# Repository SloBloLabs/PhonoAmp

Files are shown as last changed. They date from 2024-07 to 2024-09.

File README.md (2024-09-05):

# Phono Amp

Phono Amp is a RIAA compliant pre-amplifier circuit that I built into my good old Dual 626, because my living room receiver does not provide phono level inputs.

It is a very simple and straighforward design. Using KiCad simulator, component values were optimized to preserve both a nice bottom end and brilliant treble on the output.

All simulation files are contained and available in this repository.

## Small Signal Analysis from KiCad simulation
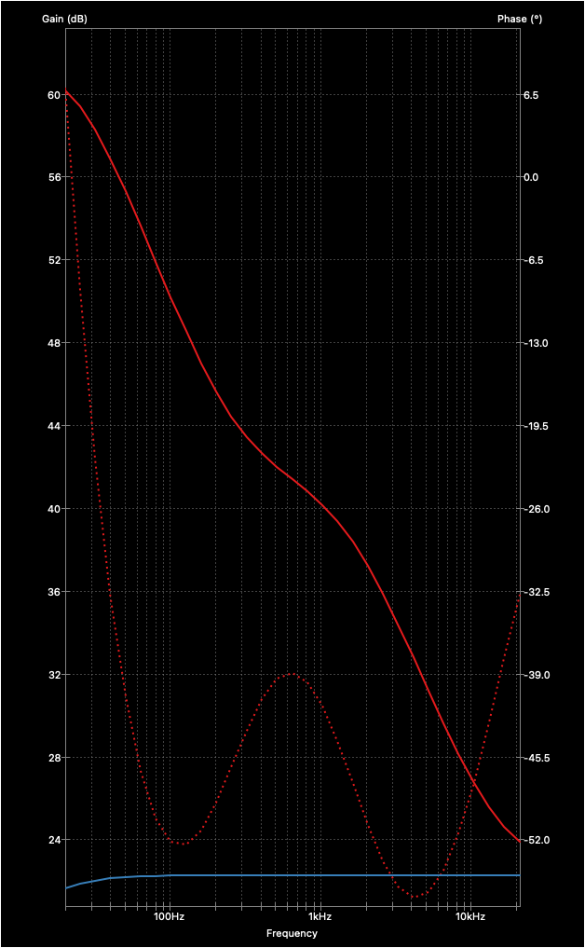
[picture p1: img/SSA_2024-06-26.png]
kicad_simulation


## The final product mounted inside the Dual 626 turntable casing
pcb1
pcb2
pcb3

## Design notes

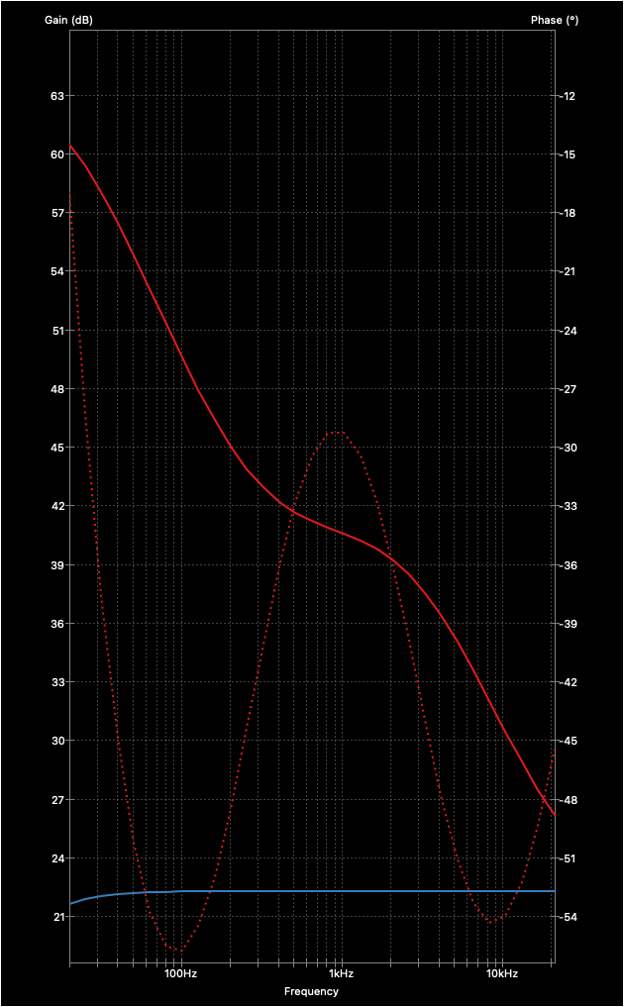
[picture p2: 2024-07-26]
img/SSA_org.png

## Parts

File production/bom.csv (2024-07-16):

Designator | Footprint | Quantity | Value | LCSC Part #
C1, C7 | C_Rect_L7.2mm_W5.5mm_P5.00mm_FKS2_FKP2_MKS2_MKP2 | 2 | 1u
C10, C4 | C_Rect_L7.2mm_W2.5mm_P5.00mm_FKS2_FKP2_MKS2_MKP2 | 2 | 1n
C11, C5 | CP_Radial_D5.0mm_P2.00mm | 2 | 2u2
C12, C6 | CP_Radial_D5.0mm_P2.00mm | 2 | 22u
C13, C14 | CP_Radial_D8.0mm_P3.50mm | 2 | 100u
C2, C8 | CP_Radial_D5.0mm_P2.00mm | 2 | 10u
C3, C9 | C_Rect_L7.2mm_W2.5mm_P5.00mm_FKS2_FKP2_MKS2_MKP2 | 2 | 10n
J1, J2 | PinHeader_1x03_P2.54mm_Vertical | 2 | Screw_Terminal_01x03
J3 | PinHeader_1x02_P2.54mm_Vertical | 1 | Screw_Terminal_01x02
R1, R8 | R_Axial_DIN0207_L6.3mm_D2.5mm_P7.62mm_Horizontal | 2 | 91k
R10, R3 | R_Axial_DIN0207_L6.3mm_D2.5mm_P7.62mm_Horizontal | 2 | 120k
R11, R4 | R_Axial_DIN0207_L6.3mm_D2.5mm_P7.62mm_Horizontal | 2 | 1M
R12, R5 | R_Axial_DIN0207_L6.3mm_D2.5mm_P7.62mm_Horizontal | 2 | 51k
R13, R6 | R_Axial_DIN0207_L6.3mm_D2.5mm_P7.62mm_Horizontal | 2 | 10k
R14, R7 | Potentiometer_Bourns_3296W_Vertical | 2 | 10k
R2, R9 | R_Axial_DIN0207_L6.3mm_D2.5mm_P7.62mm_Horizontal | 2 | 100k
U1 | DIP-8_W7.62mm_Socket_LongPads | 1 | NE5532
U2 | DIP-8_W7.62mm_Socket_LongPads | 1 | TL072

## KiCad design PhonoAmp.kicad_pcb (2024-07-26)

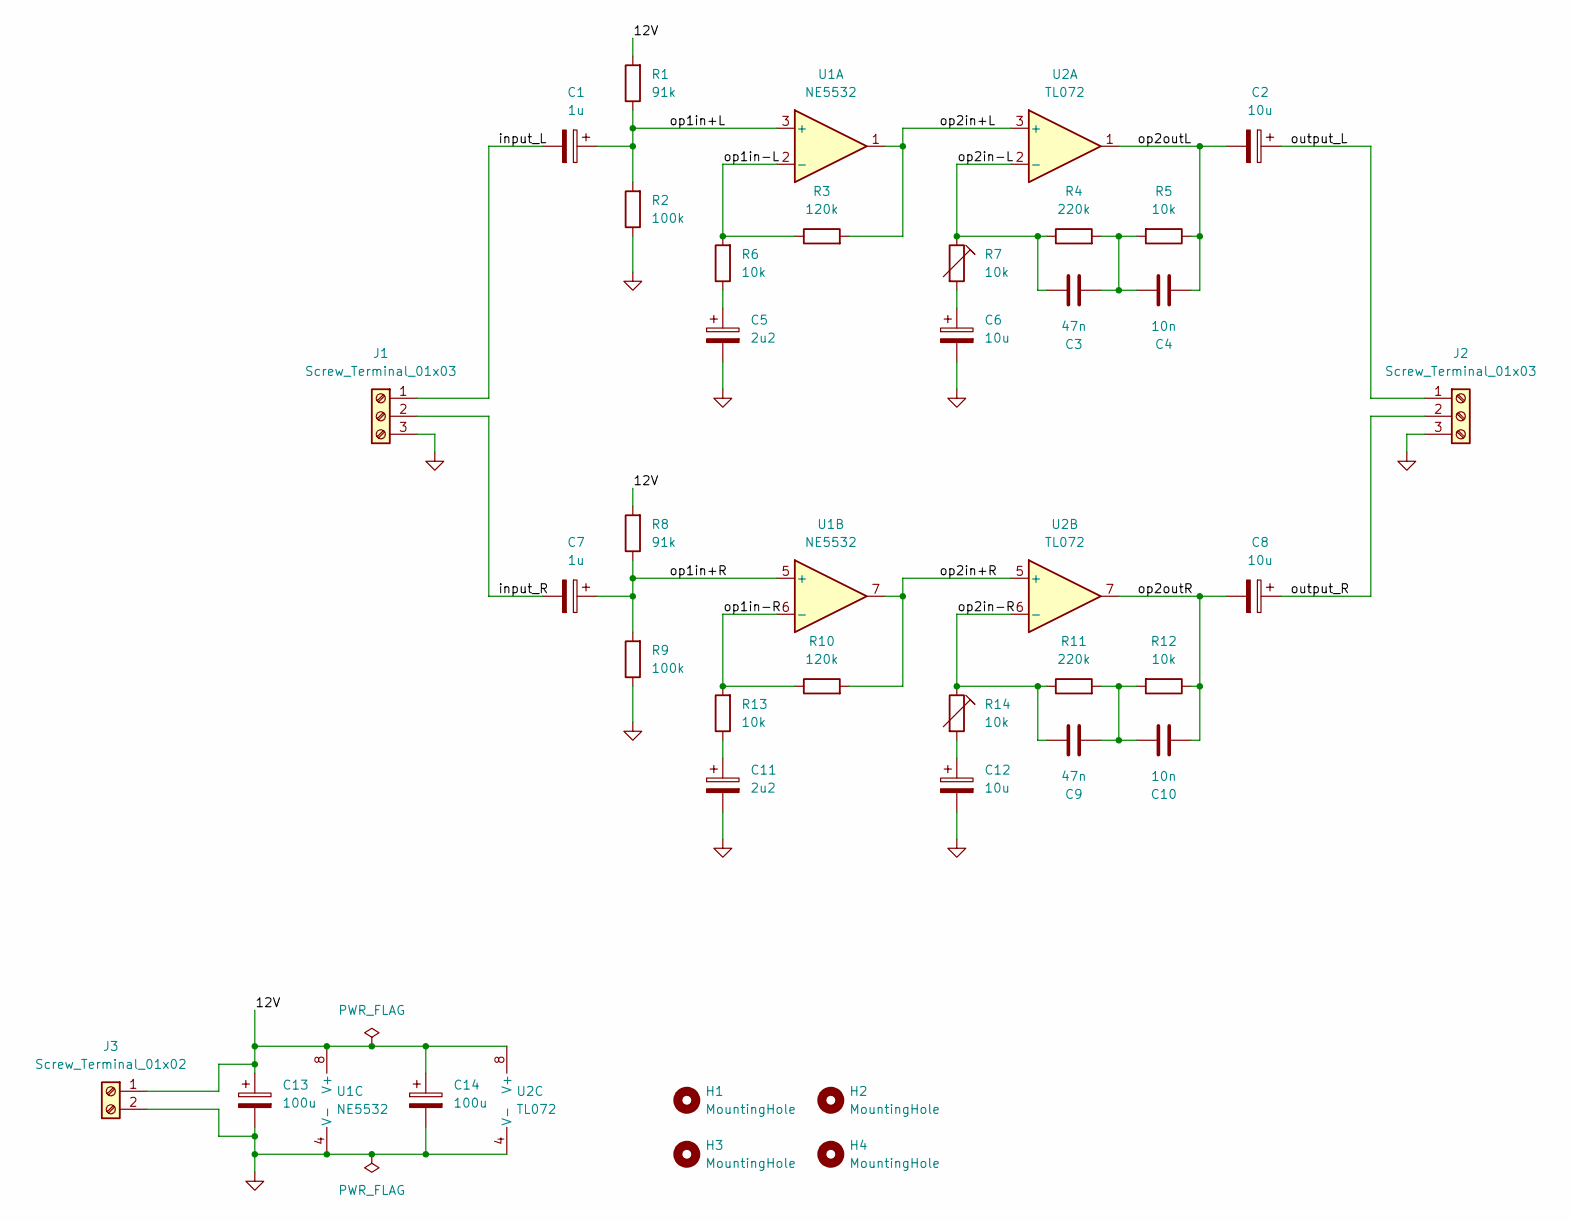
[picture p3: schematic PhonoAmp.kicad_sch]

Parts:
C1, C7: 1u; C_Rect_L7.2mm_W5.5mm_P5.00mm_FKS2_FKP2_MKS2_MKP2
C2, C6, C8, C12: 10u; CP_Radial_D5.0mm_P2.00mm
C3, C9: 47n; C_Rect_L7.2mm_W2.5mm_P5.00mm_FKS2_FKP2_MKS2_MKP2
C4, C10: 10n; C_Rect_L7.2mm_W2.5mm_P5.00mm_FKS2_FKP2_MKS2_MKP2
C5, C11: 2u2; CP_Radial_D5.0mm_P2.00mm
C13, C14: 100u; CP_Radial_D8.0mm_P3.50mm
H1, H2, H3, H4: MountingHole; MountingHole_3mm
J1, J2: Screw_Terminal_01x03; PinHeader_1x03_P2.54mm_Vertical
J3: Screw_Terminal_01x02; PinHeader_1x02_P2.54mm_Vertical
R1, R8: 91k; R_Axial_DIN0207_L6.3mm_D2.5mm_P7.62mm_Horizontal
R2, R9: 100k; R_Axial_DIN0207_L6.3mm_D2.5mm_P7.62mm_Horizontal
R3, R10: 120k; R_Axial_DIN0207_L6.3mm_D2.5mm_P7.62mm_Horizontal
R4, R11: 220k; R_Axial_DIN0207_L6.3mm_D2.5mm_P7.62mm_Horizontal
R5, R6, R12, R13: 10k; R_Axial_DIN0207_L6.3mm_D2.5mm_P7.62mm_Horizontal
R7, R14: 10k; Potentiometer_Bourns_3296W_Vertical
U1: NE5532; DIP-8_W7.62mm_Socket_LongPads
U2: TL072; DIP-8_W7.62mm_Socket_LongPads

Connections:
/12V: C13.1, C14.1, J3.1, R1.2, R8.2, U1.8 (V+), U2.8 (V+)
/input_L: C1.2, J1.1
/input_R: C7.2, J1.2
/op1in+L: C1.1, R1.1, R2.2, U1.3 (+)
/op1in+R: C7.1, R8.1, R9.2, U1.5 (+)
/op1in-L: R3.1, R6.2, U1.2 (-)
/op1in-R: R10.1, R13.2, U1.6 (-)
/op2in+L: R3.2, U1.1, U2.3 (+)
/op2in+R: R10.2, U1.7, U2.5 (+)
/op2in-L: C3.2, R4.1, R7.1, U2.2 (-)
/op2in-R: C9.2, R11.1, R14.1, U2.6 (-)
/op2outL: C2.2, C4.1, R5.1, U2.1
/op2outR: C8.2, C10.1, R12.1, U2.7
/output_L: C2.1, J2.1
/output_R: C8.1, J2.2
GND: C5.2, C6.2, C11.2, C12.2, C13.2, C14.2, J1.3, J2.3, J3.2, R2.1, R9.1, U1.4 (V-), U2.4 (V-)
unnamed: C3.1, C4.2, R4.2, R5.2
unnamed: C5.1, R6.1
unnamed: C6.1, R7.2
unnamed: C9.1, C10.2, R11.2, R12.2
unnamed: C11.1, R13.1
unnamed: C12.1, R14.2

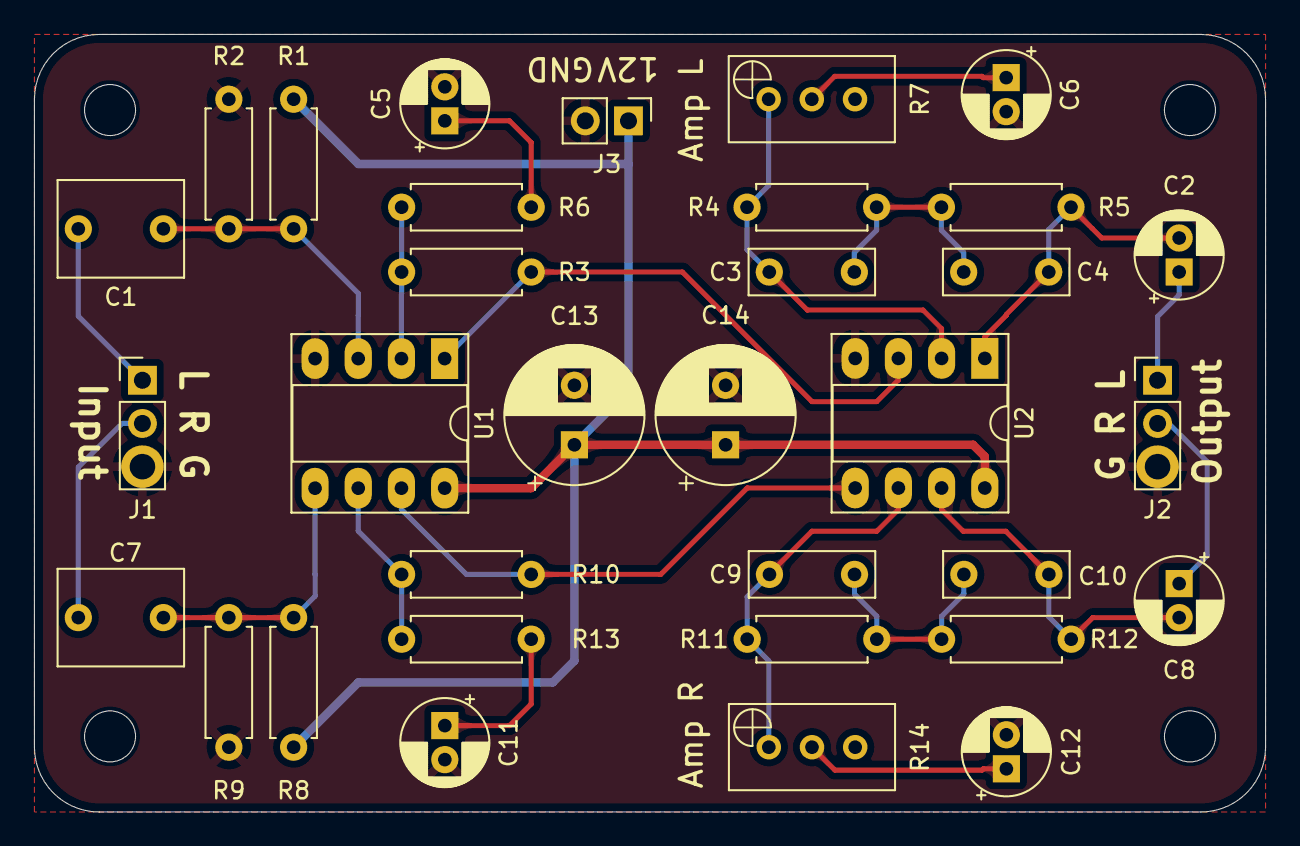
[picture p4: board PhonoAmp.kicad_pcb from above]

Board: 2 copper layers, 72.4 x 45.7 mm, 37 parts (0 on the bottom side), 22 nets.

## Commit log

2024-07-15 initial commit with simulation
    [PhonoAmp.kicad_pcb, PhonoAmp.kicad_sch, PhonoAmpSim.kicad_sch]
2024-07-16 Component Layout reviewed
    [PhonoAmp.kicad_pcb, PhonoAmp.kicad_sch]
2024-07-16 iBom Production files Transferfunctions
    [PhonoAmp.kicad_pcb, PhonoAmp.kicad_sch, PhonoAmpSim.kicad_sch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]
2024-07-17 Ordered Version 0v01 Rounded version in separate file Mounting holes aligned with Dual 626 chassis Optimized power supply tracks
    [PhonoAmp-rounded.kicad_pcb, PhonoAmp.kicad_pcb, positions.csv]
2024-07-26 Simulation and Optimization
    [PhonoAmp-rounded.kicad_pcb, PhonoAmp.kicad_pcb, PhonoAmp.kicad_sch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]
2024-09-05 Add images from the pcb built in
